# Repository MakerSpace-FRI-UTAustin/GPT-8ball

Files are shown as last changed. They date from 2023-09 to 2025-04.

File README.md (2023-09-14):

test

# GPT-8ball
This is the official repository of the GPT magic 8 ball project at UT Austin Maker Space FRI.

### **Description**

Open AI has recently made their API public to use. While many rush to make a plugin or some software with it, we here want to experiment with its usage in the physical space. 

Using an Internet connected ESP-32 and some other electronics, we can record a voice clip, send it to the API and then generate a chatGPT response.

### **Checklist**

- [ ] Get all parts
- [X] Able to record audio
- [X] Connect to the Internet and send HTTP requests
- [X] Make requests with OpenAI's API
- [X] Use a shake sensor to trigger audio recording.
- [X] Display info onto a screen.
- [ ] Able to customize the configuration of the environmental variables using WAP portal. (WiFi SSID, API keys)
- [X] Add haptics.
- [X] Make 8-ball enclosure.
- [ ] Make all necessary attributions.
- [ ] Make a step by step guide with all parts.

### **Team**
- **Rahul Myana** : [Github](https://github.com/Ramenisneat) - [rahulmyana42@gmail.com](mailto:rahulmyana42@gmail.com)

### **Parts list**
- ESP 32 Dev kit board (atleast 4Mb of Flash memory)
- MAX4466 electret microphone
- DFRobot Gravity: Shake sensor
- 16x2 lcd I2S display
- 5v power source (battery cage with buck converter)
- 3D printed enclosure (Thanks to https://Open8Ball.com.)

### **Logs**

I will update on my progress and working on this [logs](https://makerspace-fri-utaustin.github.io/GPT-8ball/docs/logs.html) site.

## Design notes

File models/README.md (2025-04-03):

These stl files are modified from models made by creators of Open8Ball
Open 8 Ball by Open8Ball is licensed under a Creative Commons Attribution 4.0 International License.
Based on a work at https://Open8Ball.com.

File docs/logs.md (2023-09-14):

## **Logs**

### Thursday - 06/08/23
- Officially created a github repo for this project.
- Finalized recording audio clips to internal SPI RAM FS.
- Connect the ESP-32 to a personal hotspot and use it to test HTTP Post requests
- Audio are too low quality. May need to get a new mic.
- Should work on making a structured code base.

video

### Wednesday - 06/14/23
- Audio is really noisy.
- Using a publically hosted audio file, I tried "recording" the audio to memory.
- Turns out the transmission is still garbled. 
- I'm pretty sure, it's because i'm writing it to flash memory simultaneously.
- Will try other methods and may have to resort to a SD card. 

### Thursday - 06/22/23
- The problem of low quality audio was due to the site I was using to test the POST request. The site allowed me to download the raw data but the data was encoded for some reason? So, I switched to a python server and sent the request on my local network. Works now.
- I tried using an SD card and it works well. But I want to try to make it work on the flash memory. I think if I can figure it out, the solution can be applicable to future projects.
- The flash write speed is slower than a SD SPI write speed. So sampling from the ADC takes longer (~18s for 10s) and introduces gaps in the audio.
- Using the flash with a slower clock also means the sample rate gets messed up andIhave to sample at lower rates.
- Testing out with ChatGPT, it seems like the ai is more than powerful enough to interpolate the missing gaps in the audio and it is working well.
- After some more testing with small audio clips, if the speaking is more or less clear and well spoken, the AI can adequately transcribe it. For the purposes of this project it is fine, but I do want to note the poor quality in the audio.

### Friday - 06/23/23
- Scrapped the HTTPClient library as there is no clear way to send the data in multi form manner.
- Oppurtunity to learn and understand how HTTP requests are formatted. The whole request is written line by line.
- Using the Root CA cert of the api,Ican establish a secure transmission
- Successful response is given.Ican parse out this text and use it for the final Chat request

### Wednesday - 06/28/23
- Expanding upon the audio transmission, the audio prompt in text is now sent to the completions API.
- ChatGPT is successfully answering the prompt.
- There were problems with memory because Arduino `String` were being used.
- After switching to C based strings,Iencountered Stack and buffer based overflows.
- Switching all C string functions such as `strcpy` to their counterpart `strncpy` fixed the errors.

### Thursday - 07/13/23
- Ordered a Shake Sensor.
- Using an interrupt handler the sensor is able to switch on the procedure.
- Moved the main code to loop() so it can be continously ran.
- The main functionality of the code is functioning properly and stress testing reveals no discernable major errors.
- I find that the mic is not as reliable as I like it to be. To be clear, it is recording poorer quality, sped up audio, but to overcome that you would need to speak pretty loud but not too close to the mic. The best fix (and frankly what should be done) is adding an SD card for the audio to be saved on but I don't want to add more chaos to the less number of headers the ESP-32 has.
- After many failed 3D prints, the 8ball enclosure is now complete. It is a modified version of open8ball.com's Arduino Uno version. I will attribute them later in the repo docs soon.

### Thursday - 07/21/23
- Got an LCD screen
- Display data and responses onto the LCD screen.
- At this point a crude prototype held with tape and dreams is done.
- The response is a little slow but that could be due to me using my phone's hotspot.
- The shake sensor is too linear. As in that there is only one axis of activation and so shaking the 8ball like a normal 8 ball doesn't work. I gotta experiment with better positions that activates the sensor properly.
- The code was getting long so I moved relevent code to relevent files and headers.

### Friday - 09/01/23
- Added WiFi provisioning using WiFiManager library on Arduino
- Can now connect the ball to any WPA2 network, this does not include our school's WPA2 Enterprise/PEAP method.

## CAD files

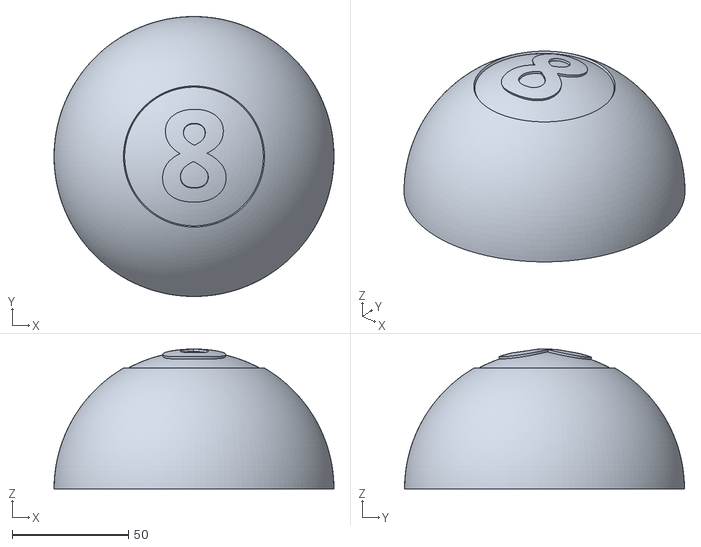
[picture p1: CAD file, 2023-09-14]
models/topHalf.stl
120.7 x 120.7 x 60.3

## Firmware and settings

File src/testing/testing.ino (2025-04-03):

#include <Arduino.h>
#include <AudioTools.h>
// #include <SPIFFS.h>
#include <FS.h>
#include <SD.h>

// #include "esp_wifi.h"

#include "secrets.h"
#include <ArduinoJson.h>
#include <LiquidCrystal_I2C.h>
#include <WiFiClientSecure.h>
#include <WiFiManager.h>

// #include <esp_wpa2.h>
#include "lcd.h"
#include "wifi.h"
#include "audio.h"

unsigned char shakenFlag = 0;
unsigned long timepoint = 0;
const int sampleSize = 10;


const int xInput = 33;
const int yInput = 35;
const int zInput = 32;

// initialize minimum and maximum Raw Ranges for each axis
int xRawMin = 512;
int xRawMax = 4095;

int yRawMin = 512;
int yRawMax = 4095;

int zRawMin = 512;
int zRawMax = 4095;

WiFiClientSecure client;


void setup(void) {
  Serial.begin(115200);

  Serial.println("Starting");
  // initialize LCD
  lcd.init();
  // turn on LCD backlight                      
  lcd.backlight();
  
  //Mic setup
  
  //FS setup; Can be substituted for SD card if needed
  if(!SD.begin(5)){
    Serial.println("SD Mount Failed");
    return;
  
}

  
  Serial.println("Wifi Setup next");

  wifiSetup();
  Serial.println("Setup Complete");

}

//Sanity check for API responses
bool checkChars(char* str){
  for (int i = 0; i < strlen(str); i++){
    if (!isAscii(str[i])){
      return false;      
    }
  }
  return true;
}

//Audio file -> text transcribtion
// Sadly manually printing the raw HTTP request to server
void sendAudio(char* prompt) {
  // Serial.println("Sending audio");
  audioFile = SD.open(filename, FILE_READ);
  audioFile.seek(0);

  //information of the API to connect to
  int port = 443;
  char* host = "api.openai.com";
  char* endpoint = "/v1/audio/transcriptions";

  //Allows for TLS handshake to occur
  
  client.setCACert(cert);
  client.setInsecure();
  Serial.println(client.connect(host, port));
  // delay(1000);


  if (!client.connected()){
    Serial.println("Issues with establishing connection to API");
    char* empty = "";
    strncpy(prompt, empty, 1);
    return;
  }

  //Some HTTP specific values
  char* boundary = "------------------------e08f77c03373314f";
  char* twohyphens = "--";
  char* newline = "\r\n";

  int newlineLength = 2;
  int boundaryLength = strlen(twohyphens) + strlen(boundary) + newlineLength;

  //Fields of the multipart-form data
  char fileDisposition[100];
  sprintf(fileDisposition, "Content-Disposition: form-data; name=\"file\"; filename=\"%s\"", filename);
  char* fileType = "Content-Type: audio/x-wav";
  char* modelDisposition = "Content-Disposition: form-data; name=\"model\"";
  char* model = "whisper-1";

  int contentLength = boundaryLength + strlen(fileDisposition) + newlineLength + strlen(fileType) + newlineLength + newlineLength + audioFile.size() + newlineLength
                      + boundaryLength + strlen(modelDisposition) + newlineLength + newlineLength + strlen(model) + boundaryLength + strlen(twohyphens) + newlineLength;


  client.print("POST ");
  client.print(endpoint);
  client.println(" HTTP/1.1");
  client.print("Host: ");
  client.println(host);
  client.println("User-Agent: ESP32");
  client.println("Accept: */*");
  client.print("Authorization: Bearer ");
  client.println(APIKEY);
  client.print("Content-Length: ");
  client.println(contentLength);
  client.print("Content-Type: multipart/form-data; boundary=");
  client.println(boundary);
  client.println();

  //Writing body of request
  client.print(twohyphens);
  client.println(boundary);
  client.println(fileDisposition);
  client.println(fileType);
  client.println();

  int start = millis();

  audioFile.seek(0);
  delay(500);

  // int test = 0;
  uint8_t buffer[1600];
  while (audioFile.available()) {
    size_t readBytes = audioFile.readBytes((char*)buffer, 1600);
    client.write(buffer, readBytes);
    // if (test == 0 ){
    //   for (int i = 0; i< readBytes; i++)
    //     Serial.print(buffer[i]);
    //     Serial.print(" ");
    // }
    // test++;
    client.flush();

  }
  client.flush();
  delay(500);
  audioFile.close();
  Serial.printf("raw sending audio bytes: %d s \n", (millis() - start)/1000);

  client.println();
  client.print(twohyphens);
  client.println(boundary);
  client.println(modelDisposition);
  client.println();
  client.println(model);
  client.print(twohyphens);
  client.print(boundary);
  client.println(twohyphens);
  client.println();

  //Parse response from server
  while (client.connected()) {
    String line = client.readStringUntil('\n');
    if (line == "\r") {
      break;
    }
  }
  char response[100];
  response[0] = '\0';
  while (client.available()) {
    char c = (char)client.read();
    strncat(response, &c, 1);
  }
  Serial.print("Response str: ");
  Serial.println(response);
  client.stop();

  StaticJsonDocument<16> doc;
  DeserializationError error = deserializeJson(doc, response, 100);

  if (error) {
    // Serial.println("deserialize error");
    strncpy(prompt, error.c_str(), strlen(error.c_str()) + 1);
    return;
  }

  const char* text = doc["text"];
  strncpy(prompt, text, strlen(text) + 1);
}

void sendPrompt(char* prompt, char* answer) {
  Serial.println("Sending prompt");
    
  //information of the API to connect to
  int port = 443;
  char* host = "api.openai.com";
  char* endpoint = "/v1/chat/completions";

  //Allows for TLS handshake to occur
  client.setCACert(cert);
  // client.setInsecure();
  client.connect(host, port);

  if (!client.connected()){
    Serial.println("Issues with establishing connection to API");
    char* empty = "";
    strncpy(answer, empty, 1);
    return;
  }

  char* payload1 = "{\"model\": \"gpt-3.5-turbo\", \"max_tokens\": 100, \"messages\": [{\"role\": \"system\", \"content\": \"You are an AI powered Magic 8 Ball, your answers should resemble a typical 8 Ball's response but can be adapted to fit the needs of the prompt. It should be really ridiculous, when acceptable. Make it around 50 characters\"}, {\"role\": \"user\", \"content\": \"";
  char* payload2 = "\"}]}";
  int payloadLength = strlen(payload1) + strlen(payload2) + strlen(prompt);

  client.print("POST ");
  client.print(endpoint);
  client.println(" HTTP/1.1");
  client.print("Host: ");
  client.println(host);
  client.println("User-Agent: ESP32");
  client.println("Accept: */*");
  client.print("Authorization: Bearer ");
  client.println(APIKEY);
  client.print("Content-Length: ");
  client.println(payloadLength);
  client.println("Content-Type: application/json");
  client.println();

  client.print(payload1);
  client.print(prompt);
  client.println(payload2);
  client.println();

  while (client.connected()) {
    String line = client.readStringUntil('\n');
    if (line == "\r") {
      Serial.println("headers received");
      break;
    }
  }
  char response[1024];
  response[0] = '\0';
  // client.read();
  // client.read();
  // client.read();
  // client.read();

  int temp = 0;
  while (client.available()) {
    char c = (char)client.read();
    if (temp > 4)
      strncat(response, &c, 1);
    else
      temp++;
  }
  client.stop();


  //WEIRD FIX

  Serial.println("Response str: ");
  Serial.println(response);

  StaticJsonDocument<2048> doc;
  DeserializationError error = deserializeJson(doc, response);


  if (error) {
    Serial.println("deserialize error");
    strncpy(answer, error.c_str(), strlen(error.c_str()));
  }
  else{

    JsonObject choices = doc["choices"][0];
    const char* message = choices["message"]["content"];

    strncpy(answer, message, strlen(message) + 1);
  }
}


int ReadAxis(int axisPin){
	long reading = 0;
	for (int i = 0; i < sampleSize; i++)
	{
	reading += analogRead(axisPin);

	}
	return reading/sampleSize;

}


int readAcc(){

  //Read raw values
	int xRaw = ReadAxis(xInput);
	int yRaw = ReadAxis(yInput);
	int zRaw = ReadAxis(zInput);


	 // Convert raw values to 'milli-Gs"
  long xScaled = map(xRaw, xRawMin, xRawMax, -1000, 1000);
  long yScaled = map(yRaw, yRawMin, yRawMax, -1000, 1000);
  long zScaled = map(zRaw, zRawMin, zRawMax, -1000, 1000);
  return sqrt(xScaled * xScaled + yScaled * yScaled +  zScaled * zScaled);



}

void loop() {
  clearWrite("Shake to ask");

  int acc = readAcc();
  Serial.print("Acc:");
  Serial.println(acc); 

  if (acc > 850){
    shakenFlag = 1;
  }


  if (shakenFlag){
    Serial.println("Triggered");
    // digitalWrite(15, HIGH);
    // delay(1000);
    // digitalWrite(15, LOW);
    clearWrite("Triggered");

    if (!recordClip()){
      clearWrite("Failed to record audio");
      goto fail;
    }


    char prompt[200];
    char answer[400];

    clearWrite("Transcribing");


    sendAudio(prompt);
    Serial.println(prompt);
    if (strcmp(prompt, "IncompleteInput") == 0 || strcmp(prompt, "InvalidInput") == 0 || strlen(prompt) == 0 || !checkChars(prompt)) {
      clearWrite("transcribe error");
      delay(5000);
      
    }
    // Serial.printf("Time taken for audio %d s \n", (millis() - start) / 1000);
    else{
      clearWrite("Generating");

      sendPrompt(prompt, answer);
      Serial.println("wroked");
      Serial.println(answer);


      marquee(answer,0);
    }
    
    // Serial.printf("Time taken for response %d s \n", (millis() - start) / 1000);
    
    fail:
    shakenFlag = 0;

    
  }
  delay(500);
}

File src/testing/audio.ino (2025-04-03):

//Setup file and encoder
bool recordSetup() {
  //Initialize the file
  Serial.println("Entering record setup");
  
  auto cfg = adc.defaultConfig(RX_MODE);
  cfg.copyFrom(info);


  if (!SD.exists(filename))
    SD.remove(filename);
  Serial.println("Delete file");

  audioFile = SD.open(filename, FILE_WRITE);
  Serial.println("open file");

  if (!audioFile) {
    Serial.println("There was an error opening the file for writing");
    return false;
  }
  //Prompts encoder to write metadata to file
  audioFile.seek(0);
  // out.setEncoder(new WAVEncoder());
  // auto cfg = out.audioInfo();
  // cfg.copyFrom(info);
  out.begin(info);
  adc.begin(cfg);



  return true;
}

bool recordClip() {
  if (!recordSetup()){
    return false;
  }
  Serial.println("starting record");

   clearWrite("Recording");

  unsigned long start = millis();
  //Records a set duration of audio by determining total file size of audio
  // for (int i = 0; i <= fileSize; i += copier.copy()) {
  // }
  copier.copyMs(duration * 1000,  info);

  Serial.printf("time taken: %d seconds\n", (millis() - start) / 1000);
  out.end();
  adc.end();

  audioFile.close();

  return true;
}

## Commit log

2023-07-22 IDK why the files didn't get added
    [audio.ino, lcd.ino, wifi.ino]
2023-09-14 stl files
    [topHalf.stl]
